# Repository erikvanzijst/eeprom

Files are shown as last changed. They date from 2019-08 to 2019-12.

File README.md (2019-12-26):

Parallel EEPROM Programmer
==========================

This is a Shield extension board for Arduino UNO R3 that adds the ability to
read and write parallel EEPROM chips.

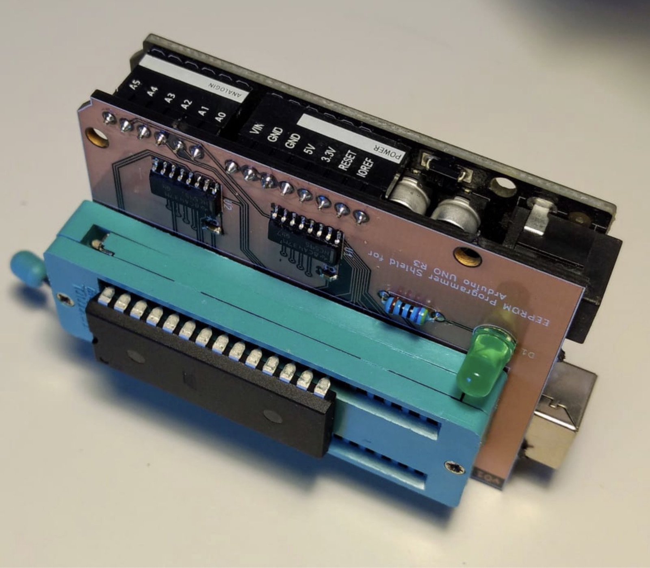
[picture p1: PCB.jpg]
PCB


This repository contains:

* Arduino code
* Interactive Python based client to read and write to the EEPROM
* KiCad scehmatic and PCB

## Installation and assembly

Install [platformio](https://platformio.org) to compile and upload the firmware
to the Arduino:

    $ platformio run --target upload

Order the PCB either directly from
[Oshpark](https://oshpark.com/shared_projects/gB4fefq3), or use the included
[Gerber files](gerbers/) with any other board house.

With the shield attached to the Uno and hooked up to a computer, fire up the
Python client. To write an image to the EEPROM:

```
$ source ./env/bin/activate
$ cat image.bin | ./eeprom.py load 
Loading 400 bytes into EEPROM...
100%
Complete.
$
```

Full writeup is at https://medium.com/@erikvanzijst/diy-eeprom-programmer-4fd11a486ea

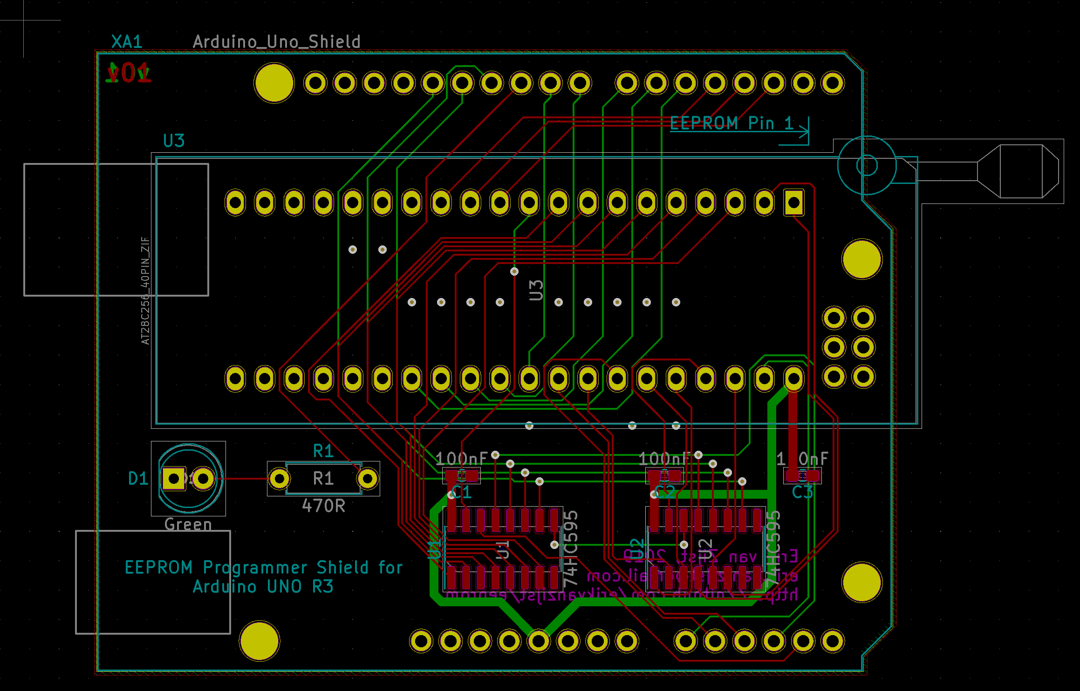
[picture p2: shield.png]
PCB Layout


The PCB can be ordered from
[OSH Park](https://oshpark.com/shared_projects/gB4fefq3).



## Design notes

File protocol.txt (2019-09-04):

Protocol

The protocol between the Python client and Arduino is a synchronous request
response based system. The client initiates all communication, one request
at a time.

Each request yields a response from the Arduino which must be consumed fully
before the next request can be sent.

Each request is packed into a structured binary envelope consisting of a
leading octet indicating the length of the message (excluding the leading
octet), followed by a single octet describing the command that is to be
executed by the Arduino, followed by 0 up to and including 62 bytes of
command-specific payload data:

   0                   1                   2                   3
   0 1 2 3 4 5 6 7 8 9 0 1 2 3 4 5 6 7 8 9 0 1 2 3 4 5 6 7 8 9 0 1
  +-+-+-+-+-+-+-+-+-+-+-+-+-+-+-+-+-+-+-+-+-+-+-+-+-+-+-+-+-+-+-+-+
  |     Length    |    Command    |              Data             |
  +-+-+-+-+-+-+-+-+-+-+-+-+-+-+-+-+-+-+-+-+-+-+-+-+-+-+-+-+-+-+-+-+

1. Command Messages

The following commands are defined:

1.1 Read

Command byte: 'r' (0x72 / ASCII 114)
Data: 16 bit address in network byte order. Since the AT28C256 has only 15
address lines, only the 15 lower bits are used. The leading, MSB is unused.

   0                   1                   2                   3
   0 1 2 3 4 5 6 7 8 9 0 1 2 3 4 5 6 7 8 9 0 1 2 3 4 5 6 7 8 9 0 1
  +-+-+-+-+-+-+-+-+-+-+-+-+-+-+-+-+-+-+-+-+-+-+-+-+-+-+-+-+-+-+-+-+
  |        3      |       'r'     |0|      15 bit address         |
  +-+-+-+-+-+-+-+-+-+-+-+-+-+-+-+-+-+-+-+-+-+-+-+-+-+-+-+-+-+-+-+-+

The response is a message containing the value at the specified address:

   0                   1
   0 1 2 3 4 5 6 7 8 9 0 1 2 3 4 5
  +-+-+-+-+-+-+-+-+-+-+-+-+-+-+-+-+
  |        1      |     value     |
  +-+-+-+-+-+-+-+-+-+-+-+-+-+-+-+-+

1.2. Write

Command byte: 'w' (0x77 / ASCII 119)
Data: 3 bytes, broken down as follows: 2 bytes containing a 15 bit address
in network byte order, followed by one octet of data to be written to the
specified address.

   0                   1                   2                   3
   0 1 2 3 4 5 6 7 8 9 0 1 2 3 4 5 6 7 8 9 0 1 2 3 4 5 6 7 8 9 0 1
  +-+-+-+-+-+-+-+-+-+-+-+-+-+-+-+-+-+-+-+-+-+-+-+-+-+-+-+-+-+-+-+-+
  |        4      |       'w'     |0|      15 bit address         |
  +-+-+-+-+-+-+-+-+-+-+-+-+-+-+-+-+-+-+-+-+-+-+-+-+-+-+-+-+-+-+-+-+
  |      Data     |
  +-+-+-+-+-+-+-+-+

The response is an acknowledgement message to indicate the operation finished
and a new command can be sent. An acknowledgement message is defined as a
single 0-byte.

1.3. Dump

Command byte: 'd' (0x64 / ASCII 100)
Data: No payload following the command byte.

   0                   1
   0 1 2 3 4 5 6 7 8 9 0 1 2 3 4 5
  +-+-+-+-+-+-+-+-+-+-+-+-+-+-+-+-+
  |        1      |       'd'     |
  +-+-+-+-+-+-+-+-+-+-+-+-+-+-+-+-+

The response is the raw contents of the entire EEPROM. This is returned as a
sequence of messages each starting with a length octet, followed by up to 63
bytes of raw payload data.

Each message is explicitly and synchronously acknowledged by the client using
a 0-byte acknowledgement message before the next message is sent.

The dump command returns exactly 32768 bytes of content at which point the
transmission is complete. The client does not respond with an acknowledgement
after the final message as no further communication will be initiated by the
circuit to warrant flow control.

1.4. Load

Command byte: 'l' (0x6C / ASCII 108)
Data: 2 bytes indicating the size of the upload that follows the request
message. Since the AT28C256 has only 15 address lines, only the lower 15 bits
are used. The leading, MSB is ignored.

   0                   1                   2                   3
   0 1 2 3 4 5 6 7 8 9 0 1 2 3 4 5 6 7 8 9 0 1 2 3 4 5 6 7 8 9 0 1
  +-+-+-+-+-+-+-+-+-+-+-+-+-+-+-+-+-+-+-+-+-+-+-+-+-+-+-+-+-+-+-+-+
  |        3      |       'l'     |0|       15 bit length         |
  +-+-+-+-+-+-+-+-+-+-+-+-+-+-+-+-+-+-+-+-+-+-+-+-+-+-+-+-+-+-+-+-+

Directly following the command message is the stream of messages each starting
with a length octet, followed by up to 63 bytes of raw payload data.

Each message is explicitly and synchronously acknowledged by the Arduino using
a 0-byte acknowledgement message before the next message is sent. This includes
the initial command message which needs to be explicitly acknowledged before
the client can proceed to send payload messages.

The command is complete once the specified number of bytes have been received.
The Arduino acknowledges the final message with a 0-byte message.

Writing always begins at address 0.

1.5 Reset

Command byte: 'r' (0x72 / ASCII 114)
Data: No payload following the command byte.

   0                   1
   0 1 2 3 4 5 6 7 8 9 0 1 2 3 4 5
  +-+-+-+-+-+-+-+-+-+-+-+-+-+-+-+-+
  |        1      |       'r'     |
  +-+-+-+-+-+-+-+-+-+-+-+-+-+-+-+-+

Immediately abort the pending operation and wait for a new command. No
acknowledgement is sent.

2.0 Flow Control

Since the Arduino's serial-over-usb port does not support hardware flow
control and has a limited 64-byte receive buffer, data is sent in discrete,
sequential segments that in most cases need to be explicitly acknowledged by
the peer before the next can be sent.

To prevent an overflow the receive buffer, the maximum segment size is 64
bytes; 1 length octet followed by at most 63 data bytes.

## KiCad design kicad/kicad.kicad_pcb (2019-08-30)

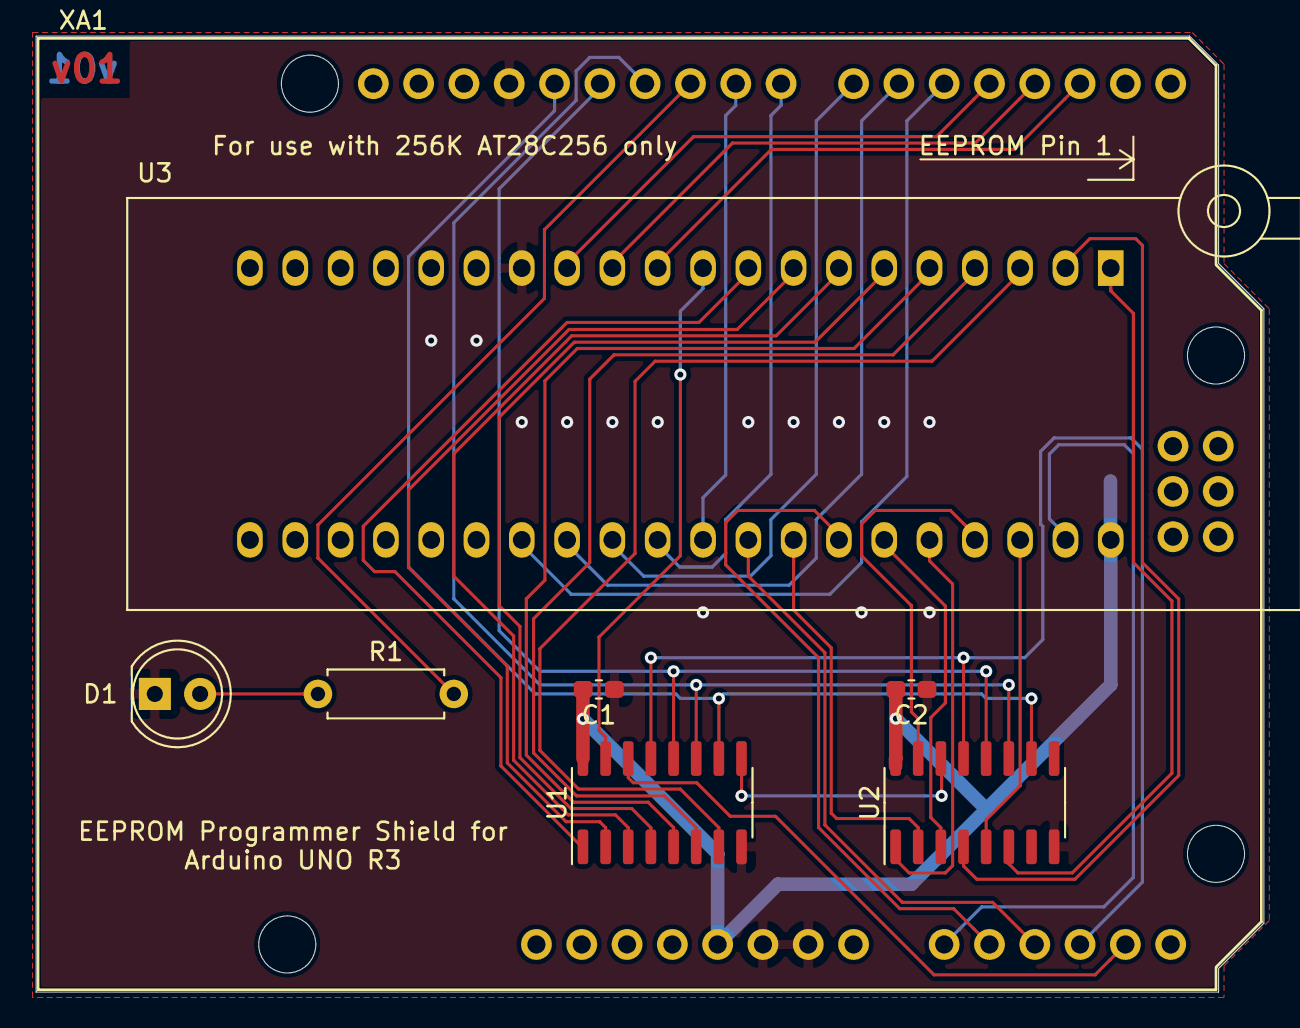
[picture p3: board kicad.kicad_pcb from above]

Board: 2 copper layers, 68.8 x 53.6 mm, 9 parts (1 on the bottom side), 36 nets.

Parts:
C1, C2, C3: 100nF; C_0603_1608Metric_Pad1.05x0.95mm_HandSolder
D1: Green; LED_D5.0mm
R1: 470R; R_Axial_DIN0207_L6.3mm_D2.5mm_P7.62mm_Horizontal
U1, U2: 74HC595; SOIC-16_3.9x9.9mm_P1.27mm
U3: AT28C256_40PIN_ZIF; DIP_Socket-40_W11.9_W12.7_W15.24_W17.78_W18.5_3M_240-1280-0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
XA1: Arduino_Uno_Shield

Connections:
/IO0: U3.11, XA1.D2
/IO1: U3.12, XA1.D3
/IO2: U3.13, XA1.D4
/IO3: U3.27, XA1.D5
/IO4: U3.28, XA1.D6
/IO5: U3.29, XA1.D7
/IO6: U3.30, XA1.D8
/IO7: U3.31, XA1.D9
/LED: R1.2, XA1.D10
/RCLK: U1.12, U2.12, XA1.D12
/SCLK: U1.11, U2.11, XA1.D11
/SER: U1.14, XA1.A4
/~CE: U3.32, XA1.A2
/~CLR: U1.10, U2.10, XA1.D13
/~OE: U3.34, XA1.A1
/~SOE: U1.13, U2.13, XA1.A3
/~WE: U3.39, XA1.A0
GND: C1.1, C2.1, C3.1, D1.1, U1.8, U2.8, U3.14, XA1.GND1, XA1.GND2, XA1.GND3
unnamed: D1.2, R1.1
unnamed: U1.1, U3.9
unnamed: U1.2, U3.8
unnamed: U1.3, U3.7
unnamed: U1.4, U3.6
unnamed: U1.5, U3.5
unnamed: U1.6, U3.4
unnamed: U1.7, U3.3
unnamed: U1.9, U2.14
unnamed: U1.15, U3.10
unnamed: U2.1, U3.36
unnamed: U2.2, U3.33
unnamed: U2.3, U3.35
unnamed: U2.4, U3.2
unnamed: U2.5, U3.38
unnamed: U2.6, U3.1
unnamed: U2.15, U3.37
VCC: C1.2, C2.2, C3.2, U1.16, U2.16, U3.40, XA1.5V1

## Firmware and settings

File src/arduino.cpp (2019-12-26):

/*
 * AT28C256 EEPROM Reader and Programmer
 * 
 * This code implements the serial wire protocol as described in protocol.txt
 * 
 * Pin Layout
 * 
 * Pin | Circuit
 * ----+--------------
 *   2 | EEPROM IO0
 *   3 | EEPROM IO1
 *   4 | EEPROM IO2
 *   5 | EEPROM IO3
 *   6 | EEPROM IO4
 *   7 | EEPROM IO5
 *   8 | EEPROM IO6
 *   9 | EEPROM IO7
 * ----+--------------
 *  A3 | 74HC595 OE
 *  A4 | 74HC595 SER
 *  11 | 74HC595 SCLK
 *  12 | 74HC595 RCLK
 *  13 | 74HC595 CLR
 * ----+--------------
 *  A0 | EEPROM WE
 *  A1 | EEPROM OE
 *  A2 | EEPROM CE
 * ----+--------------
 *  13 | Activity LED
 * ----+--------------
 *  
 * Copyright 2019, Erik van Zijst <erik.van.zijst@gmail.com>
 * 
 * Licensed under the Apache License, Version 2.0 (the "License");
 * you may not use this file except in compliance with the License.
 * You may obtain a copy of the License at
 * 
 *     http://www.apache.org/licenses/LICENSE-2.0
 * 
 * Unless required by applicable law or agreed to in writing, software
 * distributed under the License is distributed on an "AS IS" BASIS,
 * WITHOUT WARRANTIES OR CONDITIONS OF ANY KIND, either express or implied.
 * See the License for the specific language governing permissions and
 * limitations under the License.
 */
#include <Arduino.h>

enum MODE {STANDBY, READ, WRITE};
typedef enum {
  OK,
  E_RESET,      // reset command received
  E_CORRUPT,    // inbound packet corrupt
  E_UNEXPECTED, // unexpected packet received
  E_UNKNOWN     // unknown error
} error;

const unsigned int MAX_PAYLOAD = 63;
const unsigned int DELAY_US = 10;

// AT28C256 contol lines
const unsigned int EEPROM_WE = A0;
const unsigned int EEPROM_OE = A1;
const unsigned int EEPROM_CE = A2;

// 74HC595 control lines
const unsigned int SHIFT_OE = A3;
const unsigned int SHIFT_SER = A4;
const unsigned int SHIFT_RCLK = 12;
const unsigned int SHIFT_SCLK = 11;
const unsigned int SHIFT_CLR = 13;

// Activity indicator LED
const unsigned int ACT_LED = 10;

// Data pins (LSB to MSB)
const unsigned int dataPins[] = {2, 3, 4, 5, 6, 7, 8, 9};

MODE mode = STANDBY;
error errno = OK;

int receive(byte *buf, size_t len, bool sendAck);
int send(byte *buf, size_t len, bool waitForAck);
void pulse(int pin);
void loadShiftAddr(unsigned int addr);
byte readAddr(unsigned int addr);
void writeAddr(unsigned int addr, byte val);
int dump();
int load(unsigned int len);
int writeMode();
int readMode();
int standbyMode();
void processError();


void setup() {
  Serial.begin(115200);
  Serial.setTimeout(120000L);

  pinMode(EEPROM_CE, OUTPUT);
  pinMode(EEPROM_OE, OUTPUT);
  pinMode(EEPROM_WE, OUTPUT);

  pinMode(SHIFT_OE, OUTPUT);
  pinMode(SHIFT_SER, OUTPUT);
  pinMode(SHIFT_RCLK, OUTPUT);
  pinMode(SHIFT_SCLK, OUTPUT);
  pinMode(SHIFT_CLR, OUTPUT);

  digitalWrite(SHIFT_OE, LOW);
  digitalWrite(SHIFT_CLR, HIGH);

  pinMode(ACT_LED, OUTPUT);
  digitalWrite(ACT_LED, LOW);

  standbyMode();
}

/*
 * Reads the next message from the serial port and copies its payload into
 * the specified `buf` byte array.
 * 
 * This function can participate in explicit flow control by sending an
 * explicit acknowledgement message if `sendAck` is `true`.
 *
 * Returns the number of bytes that were copied into `buf` (0 for acks), or -1
 * if there was an error (check global `errno`).
 */
int receive(byte *buf, size_t len, bool sendAck) {
  int l;
  do {
    l = Serial.read();
  } while (l == -1);

  if (l > 0) {
    if (Serial.readBytes(buf, min(l, len)) != l) {
      errno = E_CORRUPT;
      return -1;
    }
  }
  if (sendAck && send(NULL, 0, false) == -1) {
    return -1;
  }
  return l;
}

/*
 * Writes the supplied bytes to the serial port, preceeding it with a length
 * octet.
 *
 * This function enforces flow control, blocking until the client has
 * acknowledged receipt with a 0-byte ack.
 *
 * Returns 0 on success, or -1 if an error occurred, in which case the global
 * `errno` variable gets set.
 */
int send(byte *buf, size_t len, bool waitForAck) {
  Serial.write(len);
  if (len > 0) {
    Serial.write(buf, len);
  }
  if (waitForAck) {
    byte buf[1 + MAX_PAYLOAD];
    int len = receive(buf, MAX_PAYLOAD, false);
    if (len != 0) {
        if (len == 1 && buf[0] == 'r') {
            // reset
            errno = E_RESET;
        } else if (len != -1) {
            errno = E_UNEXPECTED;
        }
      return -1;
    }
  }
  return 0;
}

void pulse(int pin) {
  digitalWrite(pin, HIGH);
  delayMicroseconds(DELAY_US);
  digitalWrite(pin, LOW);
  delayMicroseconds(DELAY_US);
}

/*
 * Loads the specified 16 bit address into the 595 shift register.
 */
void loadShiftAddr(unsigned int addr) {
  for (int i = 15; i >= 0; i--) {
    digitalWrite(SHIFT_SER, ((addr >> i) & 1) ? HIGH : LOW);
    delayMicroseconds(DELAY_US);
    pulse(SHIFT_SCLK);
  }
  delayMicroseconds(DELAY_US);
  pulse(SHIFT_RCLK);
}

/*
 * Returns the byte at the specified address.
 */
byte readAddr(unsigned int addr) {
  readMode();
  loadShiftAddr(addr);
  delayMicroseconds(DELAY_US);

  byte val = 0;
  for (unsigned int i = 0; i < 8; i++) {
    val |= (digitalRead(dataPins[i]) << i);
  }
  standbyMode();
  return val;
}

/*
 * Writes a single byte to the specified addess.
 * Requires IO0-IO7 to be set to OUTPUT mode, EEPROM_CE to be LOW and EEPROM_OE
 * to be HIGH prior to invocation.
 */
void writeAddr(unsigned int addr, byte val) {
  loadShiftAddr(addr);

  writeMode();

  // load data byte
  for (unsigned int i = 0; i < 8; i++) {
    digitalWrite(dataPins[i], (val >> i) & 1);
  }
  delayMicroseconds(DELAY_US);

  digitalWrite(EEPROM_WE, LOW);
  delayMicroseconds(DELAY_US);
  digitalWrite(EEPROM_WE, HIGH);

  delayMicroseconds(DELAY_US);
  standbyMode();
}

/*
 * Writes the full contents of the EEPROM to the serial port in sequential
 * messages of up to 63 bytes, waiting for explicit acknowledgement of each.
 *
 * Returns 0 on success, -1 on error, in which case the global `errno` variable
 * will be set.
 */
int dump() {
  byte payload[MAX_PAYLOAD];
  unsigned int i = 0;

  for (unsigned int addr = 0; addr < 32768; addr++) {
    i = addr % MAX_PAYLOAD;

    if (addr > 0 && i == 0) {
      // payload at capacity, send out:
      if (send(payload, sizeof(payload), true) == -1) {
        return -1;  // abort immediately
      }
    }
    payload[i++] = readAddr(addr);
  }

  if (i) {
    // send remainder
    return send(payload, i, true);
  }
  return 0;
}

/*
 * Reads the specified number of bytes from the serial port and writes them
 * to the EEPROM.
 *
 * This requires the Arduino to be in WRITE mode.
 *
 * Returns 0 on success, -1 on error, in which case the global `errno` variable
 * gets set.
 */
int load(unsigned int len) {
  unsigned int addr = 0;
  byte buf[1 + MAX_PAYLOAD];
  
  while (addr < len) {
    int cnt = receive(buf, sizeof(buf), true);
    if (cnt == -1) {
      // unexpected error; abort immediately
      return -1;
    }

    for (int i = 0; i < cnt; i++) {
      writeAddr(addr++, buf[i]);
      delay(10);
    }
  }
  return 0;
}

/*
 * Switches the pin mode for the I/O pins to OUTPUT, pulls EEPROM_CE LOW and
 * EEPROM_OE HIGH.
 *
 * Returns 0 on success, or -1 on error.
 */
int writeMode() {
  digitalWrite(EEPROM_CE, LOW);
  digitalWrite(EEPROM_OE, HIGH);
  digitalWrite(EEPROM_WE, HIGH);

  for (unsigned int i = 0; i < 8; i++) {
    pinMode(dataPins[i], OUTPUT);
  }

  delayMicroseconds(DELAY_US);
  mode = WRITE;
  return 0;
}

/**
 * Switches the pin mode for the I/O pins to INPUT, pulls EEPROM_CE LOW,
 * EEPROM_OE LOW and EEPROM_WE HIGH.
 *
 * Returns 0 on success, or -1 on error.
 */
int readMode() {
  if (mode != READ) {
    for (unsigned int i = 0; i < 8; i++) {
      pinMode(dataPins[i], INPUT);
    }
  
    digitalWrite(EEPROM_CE, LOW);
    digitalWrite(EEPROM_OE, LOW);
    digitalWrite(EEPROM_WE, HIGH);
  
    delayMicroseconds(DELAY_US);
    mode = READ;
  }
  return 0;
}

int standbyMode() {
  for (unsigned int i = 0; i < 8; i++) {
    pinMode(dataPins[i], INPUT);
  }

  digitalWrite(EEPROM_OE, LOW);
  digitalWrite(EEPROM_CE, HIGH);
  digitalWrite(EEPROM_WE, HIGH);

  delayMicroseconds(DELAY_US);
  mode = STANDBY;
  return 0;
}

/**
 * Flashes out the errno value and resets the errno variable.
 */
void processError() {
  // TODO: different patterns for different errors
  if (errno != OK) {
      for (int i = 0; i < 5; i++) {
        digitalWrite(ACT_LED, HIGH);
        delay(100);
        digitalWrite(ACT_LED, LOW);
        delay(100);
      }
  }
  // clear global error state
  errno = OK;
}

void loop() {
  if (Serial.available() > 0) {
    byte buf[1 + MAX_PAYLOAD];
    digitalWrite(ACT_LED, HIGH);

    const int len = receive(buf, sizeof(buf), false);
    if (len > 0) {
        if (buf[0] == 0x72 && len == 3) {
          byte val = readAddr((buf[1] << 8) + buf[2]);
          send(&val, 1, false);

        } else if (buf[0] == 0x77 && len == 4) {
            writeAddr((buf[1] << 8) + buf[2], buf[3]);
            // signal operation completion
            send(NULL, 0, false);

        } else if (buf[0] == 0x64 && len == 1) {
            dump();

        } else if (buf[0] == 0x6c && len == 3) {
            send(NULL, 0, false); // acknowledge cmd message
            load((buf[1] << 8) + buf[2]);

        } else if (buf[0] == 0x72 && len == 1) {
            // ignore reset command

        } else {
          errno = E_UNKNOWN;
        }
    }
    digitalWrite(ACT_LED, LOW);
  }
  processError();
}

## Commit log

2019-05-13 Arduino-Based AT28C256 EEPROM Programmer.
    Initial commit with working reads and full dumps.
2019-05-14 Added kicad schematics file.
    [kicad.kicad_pcb, kicad.sch]
2019-05-14 Renamed Arduino sketch.
2019-05-14 Added schematic.
    [kicad.sch]
2019-05-17 Serial Port Flow Control
    Since the Arduino's serial-over-USB port does not support hardware flow
    control, its tiny 64 byte receive buffer can overflow if data arrives while
    it's tending to other tasks.
    This change puts a cap on the amount of data in flight and defines a
    synchronous, explicit acknowledgement system to implement flow control.
2019-05-20 Flow Control: Added protocol modifications to client.
2019-05-21 Flow Control: Fixed bugs.
2019-08-29 KiCad: Added schematic and PCB for Arduino Shield.
2019-08-29 KiCad: Updated PCB.
    [kicad.kicad_pcb]
2019-08-29 Added silkscreen logo to PCB.
    [kicad.kicad_pcb]
2019-08-30 KiCad: Added 400dpi logo.
    [kicad.kicad_pcb]
2019-08-30 KiCad: Updated OSH Park permalink and moved cap to backside.
    [kicad.kicad_pcb]
2019-09-01 Added EEPROM chip standby mode for lower power consumption.
2019-09-04 Added EEPROM OE and CLR lines to the Arduino code.
2019-09-04 Added a reset command to interrupt long running operations.
2019-10-26 Changed PCB image in README.
2019-10-26 README: Resized PCB photo.
2019-12-26 Added Gerber files.
    [kicad-B_Cu.gbl, kicad-B_Mask.gbs, kicad-B_SilkS.gbo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]

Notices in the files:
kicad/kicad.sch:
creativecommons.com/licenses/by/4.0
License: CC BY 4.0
